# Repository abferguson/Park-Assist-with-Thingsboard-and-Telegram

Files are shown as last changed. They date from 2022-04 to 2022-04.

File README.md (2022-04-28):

# Park-Assist-with-Thingsboard-and-Telegram
An ESP8266-based device using ultrasonic sensor to help driver park car at the correct position

I ran across other maker's park assist devices and decided it might be useful for my sister. She has a tendency to park too close to the back wall of her garage resulting in damage to the wall. It is useful and it does work. I made two of these for myself.

My goal was to use the HC-SR04 ultrasonic sensor to make the measurements coupled with a 5mm LED and an LED strip to provide visual feedback of distance:
  1) Turn the LED on when the car was within range of the sensor
  2) Blink the LED white at a faster rate the closer the car was to the sensor
  3) Change the LED and WS2812B LED strip color to red, with no blinking, when the car reaches the park position.
  4) When approaching or departing, display LED strip LEDs as a function of distance: the closer the vehicle the fewer LEDs lit relative to center LED.
  5) Provide a momentary contact button on the unit to provide distance setting capability.
  6) Store the park position distance onboard the unit, using LittleFS library, in case of reboot or power failure.
  
The park assist unit is also integrated with ThingsBoard and Telegram as options.  Via ThingsBoard, the unit can be monitored for the latest network parameters, sensor readings, reboots and for errors.  Telegram notifications can be enable through Thingsboard.  The park stop distance used by the unit can also be changed through ThingsBoard.

Telegram is used to send a message to the user when the vehicle has been out of range for more than a minute. This is a potential security feature.

Additional LED effects:
After five seconds of being in the 'park' position, the 5mm LED brighness is reduced.  Additionally, a random Neopixel animation is executed for amusement for a few seconds.  the Neopixels are then turned off.

Firmware environment: Arduino IDE

Hardware: (see Fritzing file for circuit)
 1 x NodeMCU v1.0 (ESP-12E) microcontroller
 
 1 x 5mm RGB LED
 
 3 x 470 Ohm resistor (for RGB LED)
 
 1 x 10k Ohm resistor (momentary switch)
 
 1 x momentary contact tactile button
 
 1 x HC-SR04 ultrasonic sensor
 
 1 x WS2912b LED strip (I use 21 LEDs. ESP8266 can power these).
 
 1 x 470 Ohm resistor (WS2912b data line)
 
 1 x 4 channel level converter (HC-SR04 trigger and echo lines, WS2812b data line)
 
 1 x 1000 uF capacitor (for WS2812B LED strip)

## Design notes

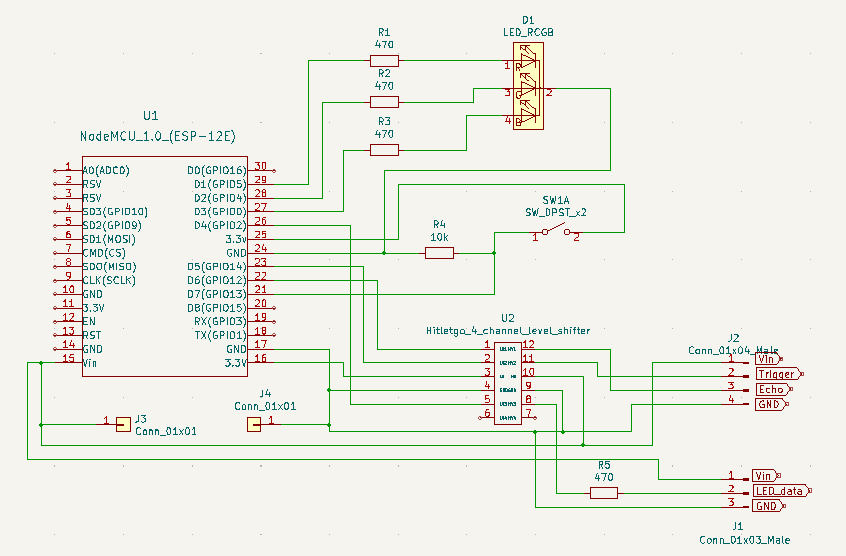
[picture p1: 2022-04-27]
KiCAD Files/Park Assist circuit.png

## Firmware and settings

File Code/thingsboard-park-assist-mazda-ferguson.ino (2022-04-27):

/* Car Parking Assistant
 Program to use the HC-SR04 ultrasonic sensor to
 measure distance to moving object (car) and blink led
 faster or slower depending on distance.  As car pulls
 into garage and approaches sensor, it starts to blink.
 As car pulls forward more, blinking speed increases.
 Once preset "stop" distance is reached, white led goes
 off and red led goes on.
 A neopixel LED strip is also used to visually indicate
 position of car relative to sensor. When car is far 
 from sensor, all LEDs light. As you apporach the stop
 position, fewer LEDs light until just before stop the
 center LED is lit.

 During startup,the 5mm LED is green until the unit successfully
 joins the network.

 Hardware:
 1 x NodeMCU v1.0 (ESP-12E) microcontroller
 1 x 5mm RGB LED
 3 x 470 Ohm resistor (for RGB LED)
 1 x 10k Ohm resistor (momentary switch)
 1 x momentary contact tactile button
 1 x HC-SR04 ultrasonic sensor
 1 x WS2912b LED strip
 1 x 470 Ohm resistor (WS2912b data line)
 1 x 4 channel level converter (HC-SR04 trigger and echo lines, WS2812b data line)
 1 x 1000 uF capacitor (for WS2812B LED strip)
 
Firmware:
Arduino IDE settings-
  NodeMCU 1.0 (ESP-12E Module)
  160 MHz   ---> per recommendation when doing SSL client stuff to handle encrypt/decrypt
  FS: 1MB OTA:~1019KB
  v2 Higher Bandwidth

**** CAUTION ****
When lighting the Neopixels at the same time as the RGB LED, avoid using analogWrite() (PWM mode).  This
causes random blinking, brightness and color changes in the Neopixel strip when nothing should be happening.

 T Ferguson
 7/3/2021

*/
///===================
// For testing, be sure to uncomment enableNotify=true at top of checkNotification()
///===================

#include "ThingsBoard.h"
#include <ESP8266WiFi.h>
#include <WiFiClientSecure.h> 
#include <ESP8266HTTPClient.h>
#include <SR04.h>
#include <WiFiUdp.h>
#include <ArduinoOTA.h>
#include <ezTime.h>
#include <ArduinoJson.h>
#include <LittleFS.h>
#include <Arduino.h>
#include <Adafruit_NeoPixel.h>
#include "credentials.h"
#include <TelegramCertificate.h>

// Enable features and capabilities
bool usesThingsboard = true;
bool usesTelegram = true;

// Code version
int fw_version = 16;

// Define variables and pins for 5mm LEDs, Neopixel strip, HC-SR04 and momentary switch
const char LEDred = 5; // D1
const char LEDgrn = 4; // D2
const char LEDblu = 0; // D3
bool ledRedOn = false;
bool ledGrnOn = false;
bool ledBluOn = false;
const char LEDpin = 2; // D4
const char TRIG_PIN = 14; // D5
const char ECHO_PIN = 12; // D6
const char BUTTON_PIN = 13; // D7

// Default LED brightness
long LEDbright = 255;

// Setup HC-SR04 sensor and related variables
SR04 sr04 = SR04(ECHO_PIN,TRIG_PIN);
int distance; // cm
float distanceft; // ft
int dialstopdist = 10; // cm, dial value
int memstopdist = 61; // default
bool sensorError = false;
bool commitFalse = false;

// Variables for handling messages
bool carOut = false;
bool carTimer = false;
bool enableNotify;
bool messageSent = false;
bool messageError = false;
char messageErrorMsg[50] = "None since reboot";

// General large char array for holding various strings temporarily
char buf[750] = "";

// Thingsboard related
bool subscribed = false;

// Telegram related
bool connectedClient;
char c;
int ch_count;
bool finishedHeaders;
bool currentLineIsBlank;
bool responseReceived;
char numChar[20] = "";
int lengthJSON;

bool Rebootstat = true;

// Timers for attribute update and IFTTT
unsigned long currentMillis = 0;
long Delaymillis = 2000;
unsigned int currentAttrMillis = 0;
int DelayAttrMillis = 60000;  // 60000
int delayAttrSec = DelayAttrMillis / 1000;
int DelayNotificationMillis = 60000; // 60000
int currentCarOutMillis = 0;

// LED related variables
bool closeTrigger = false;
bool middleTrigger = false;
bool farTrigger = false;
bool sleepLEDs = false;
int begindist = 305; // cm
int upperdelay = 80; // msec
int lowerdelay = 0; // msec
int delayval;

// WiFi related variable
int status = WL_IDLE_STATUS;

// Time related variables
Timezone myTZ;
unsigned long thingsboard_timestamp;
unsigned long bootTime;
float rebootInterval;

// Neopixel variables
int numLEDs = 21;

// Initialize ThingsBoard client
WiFiClient espClient;

// Instantiate Thingsboard client
ThingsBoardSized<600,26> tb(espClient); // Initialize ThingsBoard instance

// Instantiate NeoPixel object
Adafruit_NeoPixel strip(numLEDs, LEDpin, NEO_GRB + NEO_KHZ800);

// Telegram related
X509List cert(TELEGRAM_CERTIFICATE_ROOT);
WiFiClientSecure securedClient; // Initialize secure client for Telegram

// Function to perform reset (used only in FirstTimeRun()). Must be before setup().
void(* resetFunc) (void) = 0; // must be at top. Declare reset function @ address 0

//----------------------------------------------------------------------------------
void setup(){
  // Allow MCU to power up. Helps Serial
  delay(300);

  // Setup Neopixel pin and turn off strip
  pinMode(LEDpin, OUTPUT);
  uint32_t color = strip.Color(0,0,0);
  strip.setBrightness(20);
  strip.fill(color,0); // turn off LED strip
  strip.show();

  // Setup 5mm LED pins
  pinMode(LEDred, OUTPUT);
  pinMode(LEDgrn, OUTPUT);
  pinMode(LEDblu, OUTPUT);

  Serial.begin(115200);
  delay(300);

  Serial.println();
  Serial.println("Begin\n");

  // Show service status on serial
  if(usesThingsboard || usesTelegram) {
    Serial.println("WiFi enabled");
    initWiFi();
  }
  else {
    Serial.println("WiFi and NTP disabled");
  }

  if(usesThingsboard) {
    Serial.println("Thingsboard and OTA enabled");
  }
  else {
    Serial.println("Thingsboard and OTA disabled");
  } // else(usesThingsboard)

  if(usesTelegram){
    Serial.println("Telegram enabled");
  }
  else {
    Serial.println("Telegram disabled");
  } // else(usesTelegram)
  Serial.println();
  
  // Start LittleFS. If it does not exist create.
  Serial.println("Start LittleFS");
  boolean mounted = LittleFS.begin(); // load config if it exists. Otherwise use defaults.
  if (!mounted) {
    Serial.println("FS not formatted. Doing that now... (can last up to 30 sec)");
    LittleFS.format();
    LittleFS.begin();
    Serial.println("FS newly formatted");
    Serial.println();
  }
  else {
    Serial.println("LittleFS FS is already formatted");
    Serial.println();
  }

  // Read stopping distance from LittleFS
  readFromLittleFS();

  // Always send messages if not using Thingsboard but using Telegram
  // Thingsboard allows enableNotify to be changed
  if(!usesThingsboard && usesTelegram) {
    enableNotify = true;
  }
  
  if(usesThingsboard || usesTelegram) {
    // Start NTP service
    initNTP();

    // Add root certificate for api.telegram.org
    securedClient.setTrustAnchors(&cert);

  } // if(usesThingsboard OR usesTelegram
  
  if(usesThingsboard) {
    // Subscribe to Thingsboard
    // Program won't progress past this subroutine until Thingsboard is up and communicating
    //  so that bootTime and all other startup attributes will be captured
    subscribeThingsboard();

    // Get attributes from Thingsboard
    getClientAttributes();

    // Calculate time since last reboot
    float rbinterval = thingsboard_timestamp - bootTime;
    rebootInterval = rbinterval/86400.0; // days

    // Upload basic attributes to Thingsboard
    Attribute attributesSetup[8] = {
      { "bootTime", thingsboard_timestamp },
      { "rebootInterval", rebootInterval },
      { "fw_version", fw_version },
      { "rebootstate", Rebootstat },
      { "delayattrsec", delayAttrSec },
      { "commitFalse", commitFalse },
      { "ntpstatus", timeStatus() },
      { "lastntpupdatetime", lastNtpUpdateTime() }, 
    };
    tb.sendAttributes(attributesSetup, 8);

    // Start OTA service
    OTAsetup();
    delay(500);
  } // if(usesThingsboard)

//// test section
//  if(usesTelegram){
//    Serial.println("Sending test message");
//    sendMessage();
//  } // if(usesTelegram)
//// end test section

  // Setup pin for momentary switch
  pinMode(BUTTON_PIN, INPUT);
  int buttonState = LOW;

  // Turn down LED brightness.
  LEDbright = 50;

  // Turn on red LED. All others off.
  ledRedOn = true;
  ledGrnOn = false;
  ledBluOn = false;
  updateLED(ledRedOn, ledGrnOn, ledBluOn);
  delay(10);

  Serial.println("Going into loop");
} // void setup()

//----------------------------------------------------------------------------------

// Set value on switch 1 (Reboot toggle)
RPC_Response processSetSW1(const RPC_Data &data){
  Rebootstat = false;  // turn off reboot led
  Attribute attributesSetSW1[1] = {
    { "rebootstate", Rebootstat },
  };
  tb.sendAttributes(attributesSetSW1, 1);
  return RPC_Response(NULL, Rebootstat);
}

// Get switch 1 (Reboot toggle)
RPC_Response processGetSW1(const RPC_Data &data){
  return RPC_Response(NULL, Rebootstat);
}

// Set value on stop distance control knob
RPC_Response processSetStopDist(const RPC_Data &data){
  dialstopdist = data;
  Attribute attributesDial[1] = {
      { "stopdist", dialstopdist },
  };
  tb.sendAttributes(attributesDial, 1);
  return RPC_Response("setstop", dialstopdist);
}

// Get value of stop distance control knob
RPC_Response processGetStopDist(const RPC_Data &data){
  return RPC_Response(NULL, dialstopdist);
}

// Save stop distance to nodemcu memory (Commit Stop Distance)
RPC_Response processSetSW2(const RPC_Data &data){
  memstopdist = dialstopdist;
  Attribute attributesCommit[2] = {
    { "memstopdist", memstopdist },
    { "commitFalse", commitFalse },
  };
    tb.sendAttributes(attributesCommit, 2);
  writeToLittleFS();
  return RPC_Response(NULL, commitFalse);
}

// Get switch 2 (Reboot toggle)
RPC_Response processGetSW2(const RPC_Data &data){
  Serial.println("Set reboot toggle to off");
  return RPC_Response(NULL, commitFalse);
}

// Set enable notification toggle
RPC_Response processSetSW3(const RPC_Data &data){
//  float junk = data;
  enableNotify = data;
  Serial.print("enableNotifySet enableNotify: ");
  Serial.println(enableNotify);
  Attribute EnableNotify[1] = {
    { "enablenotify", enableNotify },
  };
  tb.sendAttributes(EnableNotify, 1);
  return RPC_Response(NULL, enableNotify);
}

// Get enable notifications toggle
RPC_Response processGetSW3(const RPC_Data &data){
  Serial.print("enableNotifyGet enableNotify: ");
  Serial.println(enableNotify);
  return RPC_Response(NULL, enableNotify);
}

int callbacksize = 8;
RPC_Callback callbacks[8] = {
  { "setSW1", processSetSW1 },
  { "getSW1", processGetSW1 },
  { "setStopDist", processSetStopDist },
  { "getStopDist", processGetStopDist },
  { "setSW2", processSetSW2 },
  { "getSW2", processGetSW2 },
  { "setSW3", processSetSW3 },
  { "getSW3", processGetSW3 },
};

//=======================================================================
void loop(){
  if(usesThingsboard || usesTelegram) {
    if (WiFi.status() != WL_CONNECTED) {
      Serial.println("WiFi reconnecting");
      reconnect();
    } 
  }

  if(usesThingsboard) {
    ArduinoOTA.handle();

    // Resubscribe to Thingsboard device and RPCs
    subscribeThingsboard();
    subscribeRPC();
  }

  // Get current distance from HC-SR04 sensor
  getSR04Distance();  

  // Set LED colors according to current distance and status
  ledHandler();

  // Check to see if momentary button is depressed. IF so, act on it
  checkButton();

  if(usesThingsboard) {
    // Send current key attributes to Thingsboard
    attributeUpdate();
    tb.loop();
  }

  // Send message out if car is out of garage
  if(usesThingsboard || usesTelegram)
    checkNotification();

  events(); // ezTime
  
} // void loop()
//=======================================================================

void checkNotification() { 
// Routine to see if message needs to be sent and to send it

///// temp in case thingsboard is true and using test device on thingsboard
//  enableNotify = true;
///// temp
//  Serial.print("enableNotify:"); Serial.println(enableNotify);
//  Serial.print("carOut:"); Serial.println(carOut);
//  Serial.print("messageSent:"); Serial.println(messageSent);

  if(enableNotify && carOut && !messageSent) {
//    Serial.println("enableNotify && carout && !messageSent");
//    Serial.print("carTimer: "); Serial.println(carTimer);
    // Start countdown timer to send message
    if(!carTimer) {
      currentCarOutMillis = millis();
      carTimer = true;
    }
    // Send message when chosen number seconds have elapsed
    // This delay allows for intermittent interruption between sensor and car without sending message
    // Example: person walking in front of sensor
    else {
      if ((unsigned long)(millis() - currentCarOutMillis) > DelayNotificationMillis) {
        sendMessage();
        Serial.println("Message sent");
        // Reset nofity timer in case message is not sent
        currentCarOutMillis = millis();
      }
    } // else(!carTimer)
  } // if(enableNotify && carOut && !messageSent)
} // void checkNotification()

void sendMessage() {
// Send message to Telegram and set various variables on response. Update Thingsboard.
//  Serial.println("In sendMessage()");

  strcpy(buf, "");
  strcat(buf, unitName);
  strcat(buf, "\nCar out of garage");

  DynamicJsonDocument jsondoc(1500);
  JsonObject jsonpayload = jsondoc.to<JsonObject>();
  
  jsonpayload["chat_id"] = chat_id;
  jsonpayload["text"] = buf;
  lengthJSON = measureJson(jsondoc);

  strcpy(buf,"");
  serializeJson(jsondoc, buf);
//  Serial.print("jsonout: "); Serial.println(jsonout);

  // Get current time from ezTime and pass to WiFiClientsecure
  unsigned long currentTime = myTZ.now();
  securedClient.setX509Time(currentTime);
  
  connectedClient = securedClient.connect("api.telegram.org", 443);

  if(!connectedClient) {
    Serial.println("Failed to connect to telegram.org");
  }
  else { // connectedClient
    securedClient.print("POST /bot");
    securedClient.print(telegram_api);
    securedClient.println("/sendMessage HTTP/1.1");
    securedClient.println("Host: api.telegram.org");
    securedClient.println("Content-Type: application/json");
    securedClient.print("Content-Length:");
    securedClient.println(lengthJSON);
    securedClient.println();

    // Send JSON message to Telegram
    securedClient.println(buf);

//    Serial.println("start of response read");
    ch_count = 0;
    finishedHeaders = false;
    currentLineIsBlank = true;
    responseReceived = false;

    while(securedClient.connected() && !finishedHeaders) {
      c = securedClient.read();
//      Serial.print(c);

      if (!finishedHeaders) {
        if (currentLineIsBlank && c == '\n') {
          finishedHeaders = true;
//          Serial.println("finishedHeaders");
        }
      }
      if (c == '\n')
        currentLineIsBlank = true;
      else if (c != '\r')
        currentLineIsBlank = false;
    } // while(securedClient.connected()

      strcpy(buf,"");
      while(securedClient.available()) {
        c = securedClient.read();
//        Serial.print(c);
        String(c).toCharArray(numChar,2);
        strcat(buf,numChar);
      }

//   Serial.println();
//   Serial.println("end of response");

    // Clean up HTTPS client instance
    securedClient.flush();
    securedClient.stop();
    Serial.print("sendTelegram post- free heap: "); Serial.println(ESP.getFreeHeap(),DEC);

    
    deserializeJson(jsondoc, buf);
//    Serial.print("sendTelegram bodydoc: "); Serial.print("buf: "); Serial.println(buf);
  
    messageSent = bool(jsondoc["ok"]);
//    Serial.print("messageSent: "); Serial.println(messageSent);

    if(messageSent) {
      messageError = false;
      strcpy(messageErrorMsg, "Success: message successfully sent");
    }
    else {
      messageError = true;
      strcpy(messageErrorMsg, "Failure: message NOT successfully sent");    
    }
//    Serial.print("  messageSent status : "); Serial.println(messageSent);
  
    // Update Thingsboard with time message successfully sent
    if(usesThingsboard && messageSent) {
      thingsboard_timestamp = myTZ.tzTime(myTZ.now(),LOCAL_TIME);
      Attribute messageSentUpdate[1] = {
        { "messageSenttime", thingsboard_timestamp },
      };
      tb.sendAttributes(messageSentUpdate, 1);
    }
  } // connectedClient

//  Serial.println("End sendMessage()\n");
} // void sendMessage()

void getSR04Distance() {
// Read distance from HC-SR04 sensor and set sensor error state
  distance = sr04.Distance();
  distanceft = distance*0.0328084;
//  Serial.println(distanceft);
  if (distance <= 0) {
    Serial.print("Bad sensor. Distance = "); Serial.println(distance);
    sensorError = true;
  }
  else {
    sensorError = false;
  }
} // void getSR04Distance()

void checkButton() {
// Check if momentary button is pressed
  // Read state of button pin
  int buttonState = digitalRead(BUTTON_PIN);

  // If pin state is high (button pressed), read and save distance from HC-SR04 sensor to LittleFS
  if (buttonState == HIGH) {
    Serial.println("button on");
    dialstopdist = distance;
    memstopdist = distance;
    writeToLittleFS();
    Serial.print("Button-saved stop distance to LittleFS memory: "); Serial.println(memstopdist);
  }
}  // void checkButton()
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
